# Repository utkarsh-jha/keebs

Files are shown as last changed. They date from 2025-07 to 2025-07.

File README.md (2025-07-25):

> **⚠️ CRITICAL R1 PCB ISSUE:**
> - **R1 PCBs have a serious design flaw** where one of the columns is routed to the GND pin instead of a GPIO pin.
> - **Manual fix required**: You must manually jump the affected column to pin 23 (GP17) to make the keyboard functional.
> - This issue will be fixed in future revisions. The repository will be updated once R2 PCBs are available.

> **Disclaimer:**
> - **This is a work in progress!**
> - This project is provided as-is, with no guarantees or warranties. Use at your own risk.
> - I am not responsible for any damage, loss, or issues arising from the use, assembly, or modification of these designs.
> - Please verify all information and double-check pinouts, connections, and manufacturing details before proceeding.

# Keebs Project
Welcome to the **Keebs Project**! This is a collection of custom keyboard projects, with a focus on unique, open-source designs for keyboard enthusiasts and makers.

## Featured Project: Polygyatt

**Polygyatt** is a steno + QMK compatible keyboard designed for both stenography and regular typing. It is fully open-source and aims to be accessible for DIY builders and tinkerers.

### Key Features
- **Steno + QMK Compatible**: Use it for stenography or as a regular keyboard.
- **Open Source**: All design files, firmware, and documentation are available.
- **DIY Friendly**: Designed for easy assembly and customization.

### Project Structure
- `polygyatt/PCB/` — KiCad PCB and schematic files
- `polygyatt/QMK/` — QMK firmware and configuration
- `polygyatt/JAVELIN/` — Steno Firmware and configuration

### Images
#### Polygyatt Back
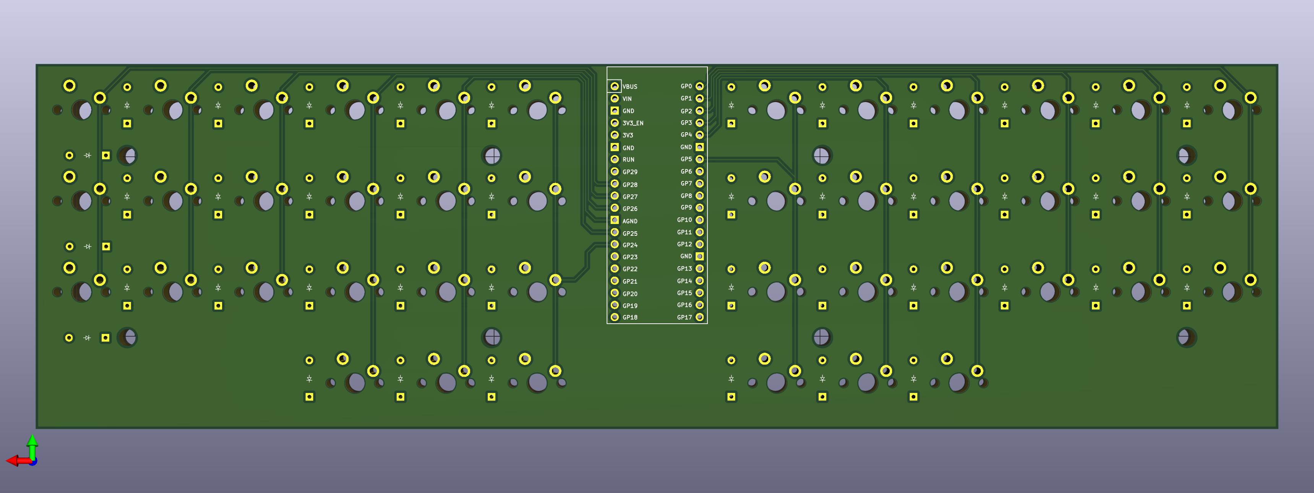
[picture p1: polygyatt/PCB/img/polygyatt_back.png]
Polygyatt Back


#### Polygyatt Front
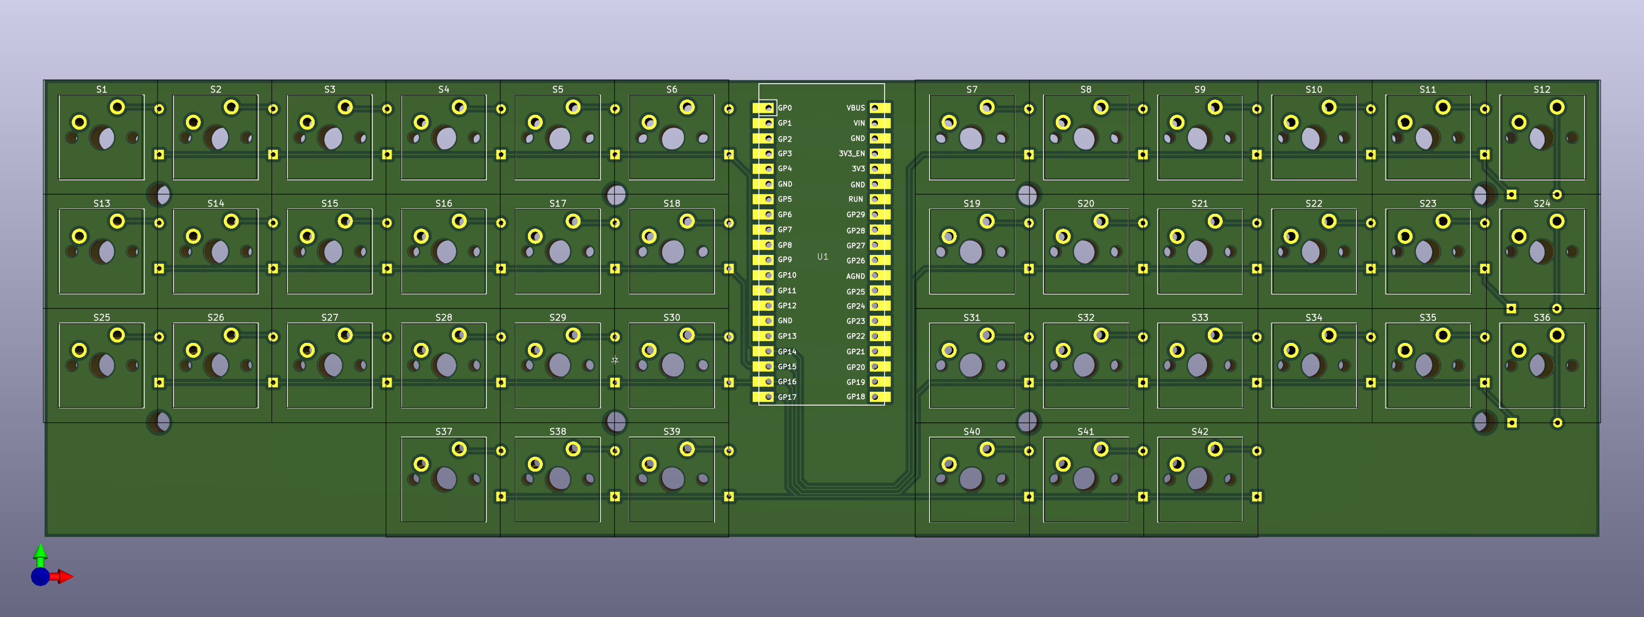
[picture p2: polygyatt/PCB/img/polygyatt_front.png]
Polygyatt Front


---

## Getting Started
1. **Browse the Polygyatt folder** for design files and documentation.
2. **Check out the QMK folder** for firmware and keymap info.
3. **See the production folder** for manufacturing files (BOM, positions, etc).

## License
This project is open source. See individual folders for license details.

## Contributing
Contributions, suggestions, and improvements are welcome! Please open an issue or submit a pull request.

---

For more information, see the `polygyatt/README.md`.

## Credits
This keyboard project is heavily inspired by the [Polyglot Keyboard](https://stenokeyboards.com/products/polyglot-keyboard) by StenoKeyboards. Many design choices and features are based on or adapted from the Polyglot project.
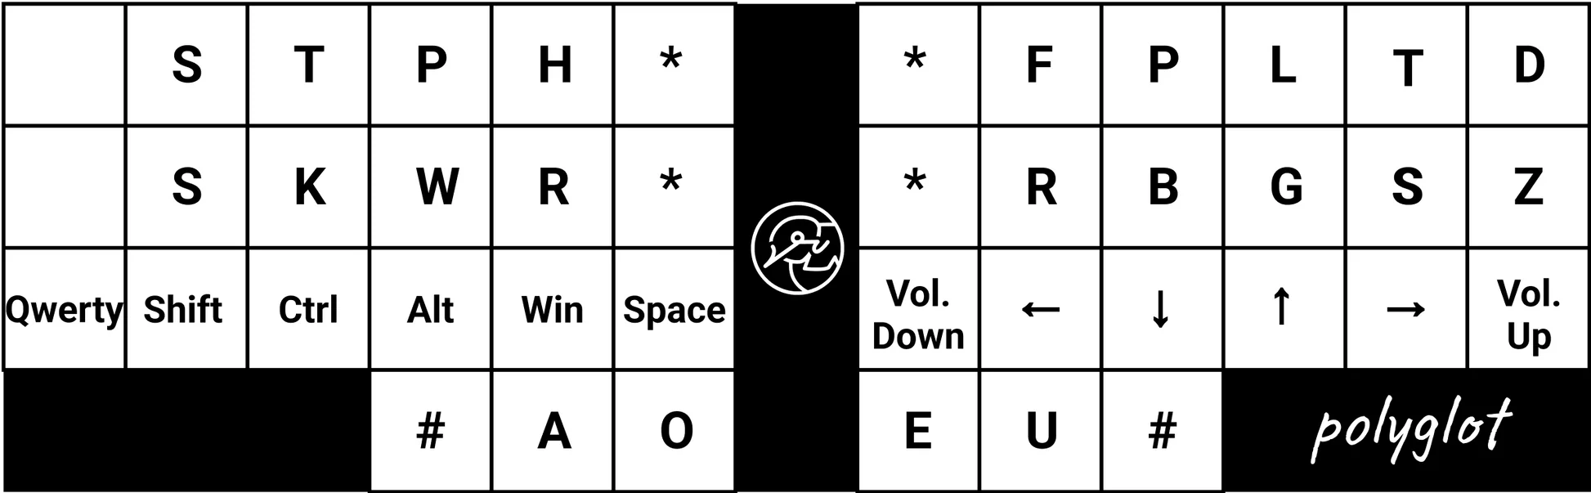
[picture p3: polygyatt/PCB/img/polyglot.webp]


## Silk Screen Attribution
The PCB silk screen art and graphics are credited to their respective creators. If you use or modify the silk screen designs, please retain attribution where possible.

Silk screen art source: [Wormhole Vectors by Vecteezy](https://www.vecteezy.com/free-vector/wormhole)

---

## Note
> ⚠️ **Alert:** This project will **not** be supported on a regular Raspberry Pi Pico, as the pinouts are different from the required configuration.

#### Pico Pinout Reference
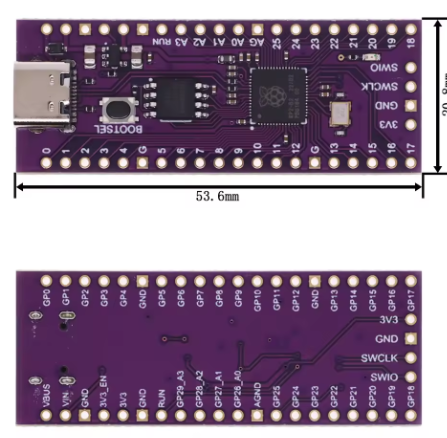
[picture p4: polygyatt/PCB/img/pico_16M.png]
Pico 16M Pinout


## Update
| Date | Event |
|---|---|
| 6th July 2025  | PCB protos ordered |
| 25th July 2025  | PCB has a design flaw where one of the pins is routed to GND and havent tested the pico steno mode since the MCU I have is using a Zetta based flash chip (the official repos supporst Winbond chip) |

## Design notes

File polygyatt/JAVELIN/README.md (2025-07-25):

# Polygyatt Javelin Steno Setup

This README provides instructions for setting up the Polygyatt keyboard with Javelin steno firmware.

## Prerequisites

Before starting, make sure you have the following installed:
- Git
- CMake (version 3.12 or higher)
- GCC ARM toolchain
- Python 3

## Setup Instructions

### 1. Clone the Javelin Steno Pico Repository

First, clone the javelin-steno-pico repository from GitHub and complete the setup mentioned there:

```bash
git clone https://github.com/jthlim/javelin-steno-pico.git
cd javelin-steno-pico
```

### 2. Copy Board Configuration

Copy the `polygyatt.h` file from this directory to the `config` folder of the javelin-steno-pico repository:

```bash
cp /path/to/your/polygyatt/JAVELIN/polygyatt.h ./config/
```

Replace `/path/to/your/polygyatt/JAVELIN/` with the actual path to this directory.

### 3. Build the Firmware

Create a build directory and compile the firmware:

```bash
mkdir build
cd build
cmake .. -DJAVELIN_BOARD=polygyatt
make
```

### 4. Flash the Firmware

After successful compilation, you'll find the firmware file (`polygyatt.uf2`) in the build directory. To flash it to your Polygyatt keyboard:

1. Hold the BOOTSEL button on your RP2040-based Polygyatt keyboard while connecting it to your computer
2. The keyboard should appear as a USB mass storage device
3. Copy the `polygyatt.uf2` file to the mounted device
4. The keyboard will automatically reboot with the new firmware

## Troubleshooting

- If you encounter build errors, ensure all prerequisites are properly installed
- Make sure the `polygyatt.h` file is correctly placed in the `config` directory
- Verify that the CMake command includes the correct board specification: `-DJAVELIN_BOARD=polygyatt`

## Additional Resources

- [Javelin Steno Pico Repository](https://github.com/jthlim/javelin-steno-pico)
- [Plover Steno Software](https://www.openstenoproject.org/plover/)

For more information about stenography and the Javelin firmware, visit the main repository documentation.

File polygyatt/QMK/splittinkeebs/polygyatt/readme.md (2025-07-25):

# Scotto34 (PCB Edition)

Scotto34 (PCB Edition)

A low profile 34-key split monoblock ortholinear keyboard that uses 18x17mm spaced Choc switches and an exposed controller in the middle.

*   Keyboard Maintainer: [Joe Scotto](https://github.com/joe-scotto)
*   Hardware Supported: Scotto34 (PCB Edition), Raspberry Pi Pico
*   Hardware Availability: [ScottoKeebs](https://scottokeebs.com), [Amazon](https://amazon.com), [AliExpress](https://aliexpress.com)

# Compiling

Make example for this keyboard (after setting up your build environment):

    make scottokeebs/scotto34:default

Flashing example for this keyboard:

    make scottokeebs/scotto34:default:flash

See the [build environment setup](https://docs.qmk.fm/#/getting_started_build_tools) and the [make instructions](https://docs.qmk.fm/#/getting_started_make_guide) for more information. Brand new to QMK? Start with our [Complete Newbs Guide](https://docs.qmk.fm/#/newbs).

# Bootloader

Enter the bootloader in 3 ways:

*   **Bootmagic reset**: Hold down the key at (0,0) in the matrix (usually the top left key or Escape) and plug in the keyboard
*   **Physical reset button**: Briefly press the button on the back of the PCB - some may have pads you must short instead
*   **Keycode in layout**: Press the key mapped to `QK_BOOT` if it is available

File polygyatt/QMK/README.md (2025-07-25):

# Polygyatt QMK/Vial Setup

This README provides instructions for setting up the Polygyatt keyboard with QMK firmware and Vial support.

## Prerequisites

Before starting, make sure you have the following installed:
- Git
- Python 3.7 or higher
- QMK CLI tools

## Setup Instructions

### 1. Clone the QMK Vial Repository

First, clone the QMK Vial repository from GitHub:

```bash
git clone https://github.com/vial-kb/vial-qmk.git
cd vial-qmk
```

### 2. Complete QMK Setup

Set up the QMK environment by running the setup command:

```bash
qmk setup
```

This will install the necessary dependencies and configure your QMK environment.

### 3. Copy Keyboard Configuration

Copy the `splittinkeebs` folder from this directory to the `keyboards` folder in your QMK installation:

```bash
cp -r /path/to/your/polygyatt/QMK/splittinkeebs ./keyboards/
```

Replace `/path/to/your/polygyatt/QMK/` with the actual path to this directory.

Alternatively, you can create a symbolic link (recommended for development):

```bash
ln -s /path/to/your/polygyatt/QMK/splittinkeebs ./keyboards/splittinkeebs
```

### 4. Compile the Firmware

Compile the Vial-compatible firmware for the Polygyatt keyboard:

```bash
qmk compile -kb splittinkeebs/polygyatt -km vial
```

### 5. Flash the Firmware

After successful compilation, you'll find the firmware file (`.uf2` or `.hex`) in the QMK build directory. To flash it to your Polygyatt keyboard:

#### For RP2040-based boards (UF2 method):
1. Hold the BOOTSEL button on your Polygyatt keyboard while connecting it to your computer
2. The keyboard should appear as a USB mass storage device
3. Copy the generated `.uf2` file to the mounted device
4. The keyboard will automatically reboot with the new firmware

#### Alternative flashing method:
```bash
qmk flash -kb splittinkeebs/polygyatt -km vial
```

## Using Vial

Once the firmware is flashed:

1. Download and install [Vial](https://get.vial.today/)
2. Connect your Polygyatt keyboard
3. Open Vial - it should automatically detect your keyboard
4. Customize your keymap, rotary encoders, and other features in real-time

## Available Keymaps

- `default` - Basic keymap configuration
- `vial` - Vial-compatible keymap with real-time customization support

## Troubleshooting

- If you encounter build errors, ensure QMK is properly set up with `qmk doctor`
- Make sure the `splittinkeebs` folder is correctly placed in the `keyboards` directory
- Verify that the compile command uses the correct keyboard path: `splittinkeebs/polygyatt`
- If Vial doesn't detect your keyboard, ensure you flashed the `vial` keymap, not the `default` one

## Additional Resources

- [QMK Documentation](https://docs.qmk.fm/)
- [Vial Documentation](https://get.vial.today/docs/)
- [QMK Vial Repository](https://github.com/vial-kb/vial-qmk)

For more information about QMK configuration and advanced features, visit the official QMK documentation.

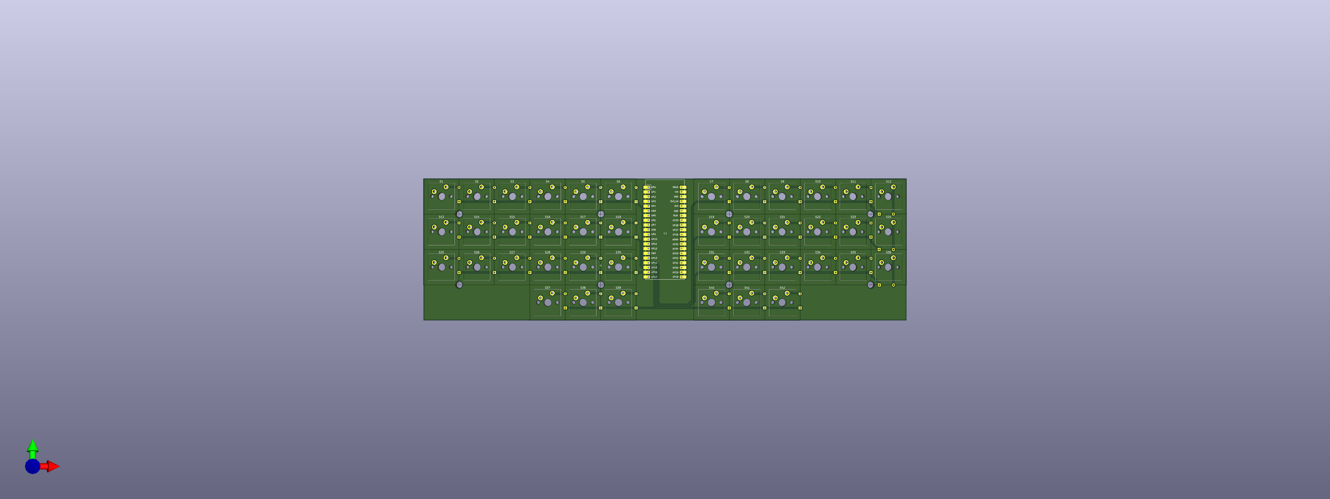
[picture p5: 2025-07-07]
polygyatt/PCB/polygyatt.png

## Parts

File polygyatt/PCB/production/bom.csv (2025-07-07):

Designator | Footprint | Quantity | Value | LCSC Part #
D1, D10, D11, D12, D13, D14, D15, D16, D17, D18, D19, D2, D20, D21, D22, D23, D24, D25, D26, D27, D28, D29, D3, D30, D31, D32, D33, D34, D35, D36, D37, D38, D39, D4, D40, D41, D42, D5, D6, D7, D8, D9 | Diode_DO-35 | 42 | Diode
S1, S10, S11, S12, S13, S14, S15, S16, S17, S18, S19, S2, S20, S21, S22, S23, S24, S25, S26, S27, S28, S29, S3, S30, S31, S32, S33, S34, S35, S36, S37, S38, S39, S4, S40, S41, S42, S5, S6, S7, S8, S9 | MX_PCB_1.00u | 42 | Keyswitch
SLKSCREEN1 | silk_screen_art_bitmap | 1 | ~
U1 | Pi_Pico_16M | 1 | Raspberry_Pi_Pico

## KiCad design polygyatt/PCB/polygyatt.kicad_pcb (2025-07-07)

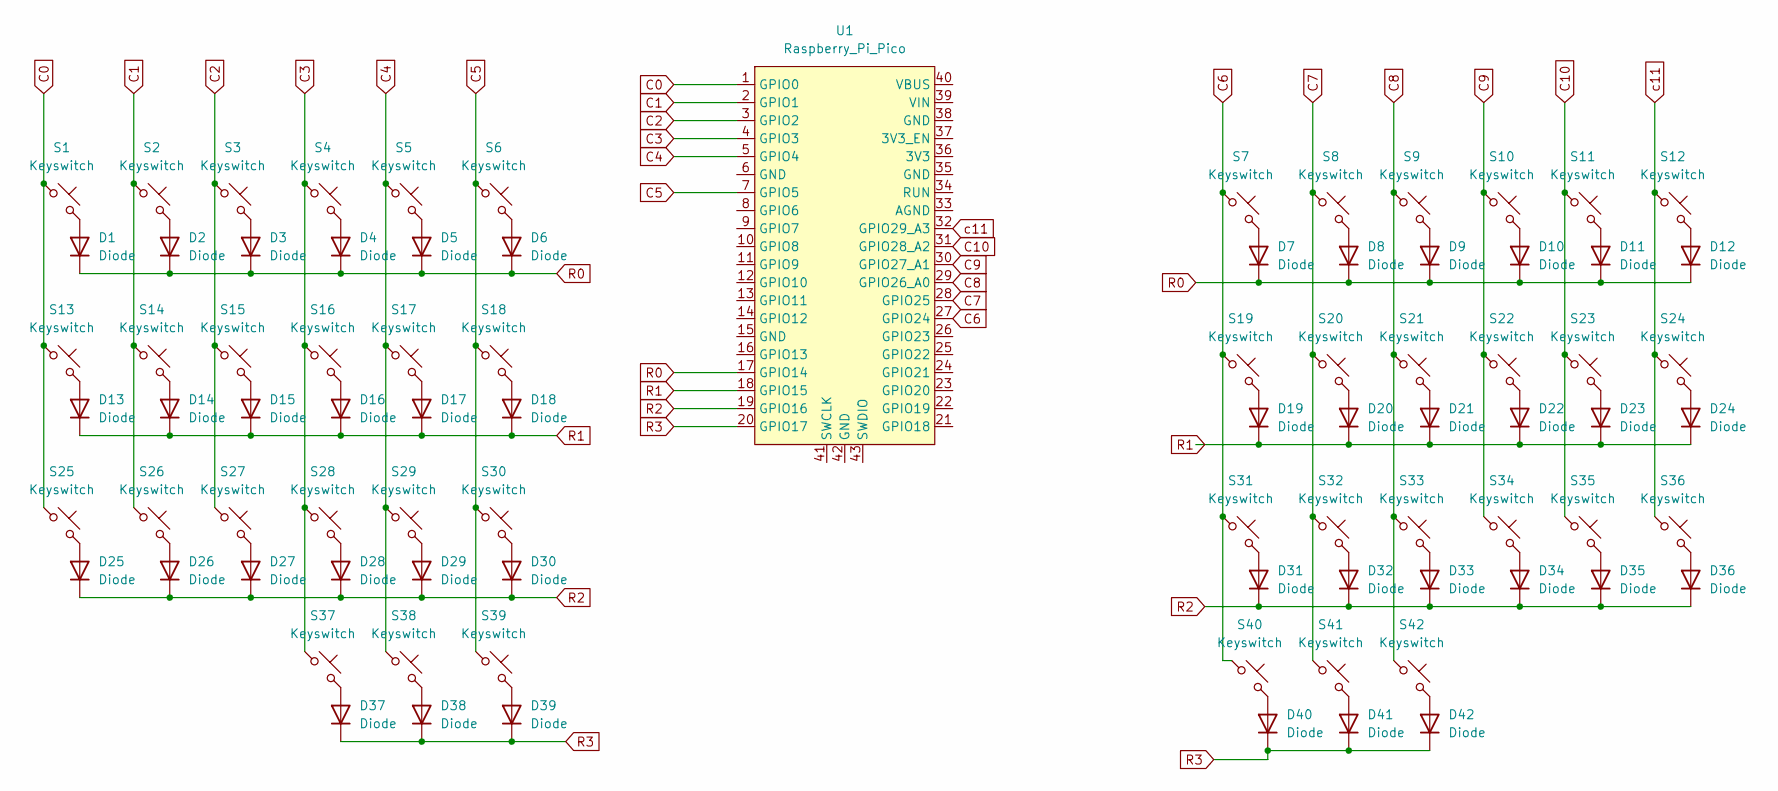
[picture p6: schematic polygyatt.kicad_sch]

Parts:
D1, D2, D3, D4, D5, D6, D7, D8, D9, D10, D11, D12, D13, D14, D15, D16, D17, D18, D19, D20, D21, D22, D23, D24, D25, D26, D27, D28, D29, D30, D31, D32, D33, D34, D35, D36, D37, D38, D39, D40, D41, D42: Diode; Diode_DO-35
S1, S2, S3, S4, S5, S6, S7, S8, S9, S10, S11, S12, S13, S14, S15, S16, S17, S18, S19, S20, S21, S22, S23, S24, S25, S26, S27, S28, S29, S30, S31, S32, S33, S34, S35, S36, S37, S38, S39, S40, S41, S42: Keyswitch; MX_PCB_1.00u
U1: Raspberry_Pi_Pico; Pi_Pico_16M
slkscreen1: silk_screen_art_bitmap

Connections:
C0: S1.1, S13.1, S25.1, U1.1 (GPIO0)
C1: S2.1, S14.1, S26.1, U1.2 (GPIO1)
C2: S3.1, S15.1, S27.1, U1.3 (GPIO2)
C3: S4.1, S16.1, S28.1, S37.1, U1.4 (GPIO3)
C4: S5.1, S17.1, S29.1, S38.1, U1.5 (GPIO4)
C5: S6.1, S18.1, S30.1, S39.1, U1.7 (GPIO5)
C6: S7.1, S19.1, S31.1, S40.1, U1.27 (GPIO24)
C7: S8.1, S20.1, S32.1, S41.1, U1.28 (GPIO25)
C8: S9.1, S21.1, S33.1, S42.1, U1.29 (GPIO26_A0)
C9: S10.1, S22.1, S34.1, U1.30 (GPIO27_A1)
C10: S11.1, S23.1, S35.1, U1.31 (GPIO28_A2)
unnamed: D1.2 (A), S1.2
unnamed: D2.2 (A), S2.2
unnamed: D3.2 (A), S3.2
unnamed: D4.2 (A), S4.2
unnamed: D5.2 (A), S5.2
unnamed: D6.2 (A), S6.2
unnamed: D7.2 (A), S7.2
unnamed: D8.2 (A), S8.2
unnamed: D9.2 (A), S9.2
unnamed: D10.2 (A), S10.2
unnamed: D11.2 (A), S11.2
unnamed: D12.2 (A), S12.2
unnamed: D13.2 (A), S13.2
unnamed: D14.2 (A), S14.2
unnamed: D15.2 (A), S15.2
unnamed: D16.2 (A), S16.2
unnamed: D17.2 (A), S17.2
unnamed: D18.2 (A), S18.2
unnamed: D19.2 (A), S19.2
unnamed: D20.2 (A), S20.2
unnamed: D21.2 (A), S21.2
unnamed: D22.2 (A), S22.2
unnamed: D23.2 (A), S23.2
unnamed: D24.2 (A), S24.2
unnamed: D25.2 (A), S25.2
unnamed: D26.2 (A), S26.2
unnamed: D27.2 (A), S27.2
unnamed: D28.2 (A), S28.2
unnamed: D29.2 (A), S29.2
unnamed: D30.2 (A), S30.2
unnamed: D31.2 (A), S31.2
unnamed: D32.2 (A), S32.2
unnamed: D33.2 (A), S33.2
unnamed: D34.2 (A), S34.2
unnamed: D35.2 (A), S35.2
unnamed: D36.2 (A), S36.2
unnamed: D37.2 (A), S37.2
unnamed: D38.2 (A), S38.2
unnamed: D39.2 (A), S39.2
unnamed: D40.2 (A), S40.2
unnamed: D41.2 (A), S41.2
unnamed: D42.2 (A), S42.2
R0: D1.1 (K), D2.1 (K), D3.1 (K), D4.1 (K), D5.1 (K), D6.1 (K), D7.1 (K), D8.1 (K), D9.1 (K), D10.1 (K), D11.1 (K), D12.1 (K), U1.17 (GPIO14)
R1: D13.1 (K), D14.1 (K), D15.1 (K), D16.1 (K), D17.1 (K), D18.1 (K), D19.1 (K), D20.1 (K), D21.1 (K), D22.1 (K), D23.1 (K), D24.1 (K), U1.18 (GPIO15)
R2: D25.1 (K), D26.1 (K), D27.1 (K), D28.1 (K), D29.1 (K), D30.1 (K), D31.1 (K), D32.1 (K), D33.1 (K), D34.1 (K), D35.1 (K), D36.1 (K), U1.19 (GPIO16)
R3: D37.1 (K), D38.1 (K), D39.1 (K), D40.1 (K), D41.1 (K), D42.1 (K), U1.20 (GPIO17)
c11: S12.1, S24.1, S36.1, U1.32 (GPIO29_A3)

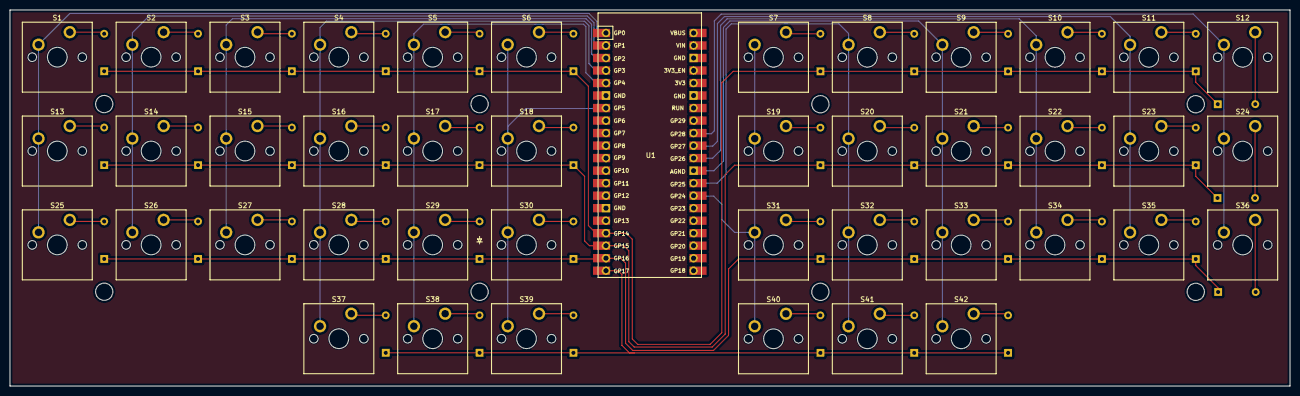
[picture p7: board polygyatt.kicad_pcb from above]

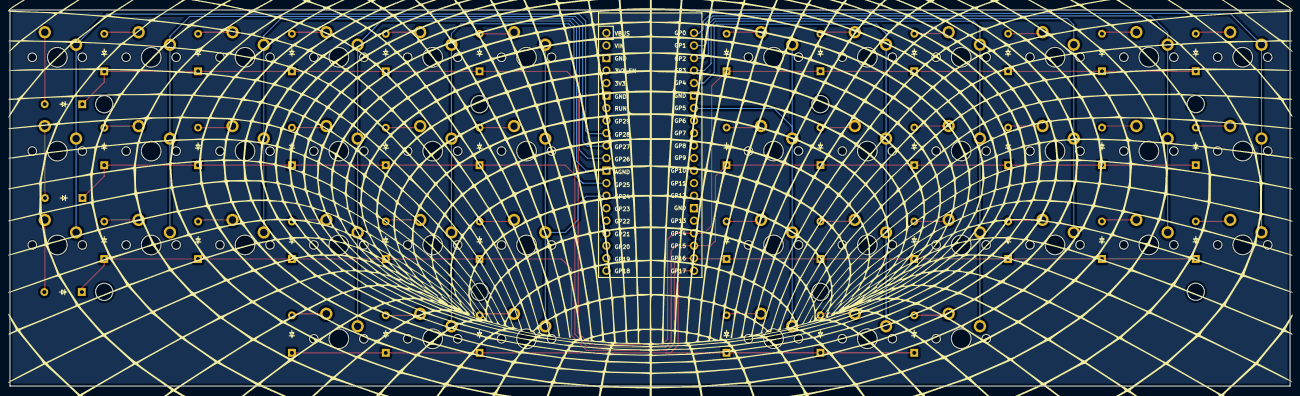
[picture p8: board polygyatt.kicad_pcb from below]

Board: 2 copper layers, 259.9 x 76.3 mm, 86 parts (41 on the bottom side), 58 nets.
